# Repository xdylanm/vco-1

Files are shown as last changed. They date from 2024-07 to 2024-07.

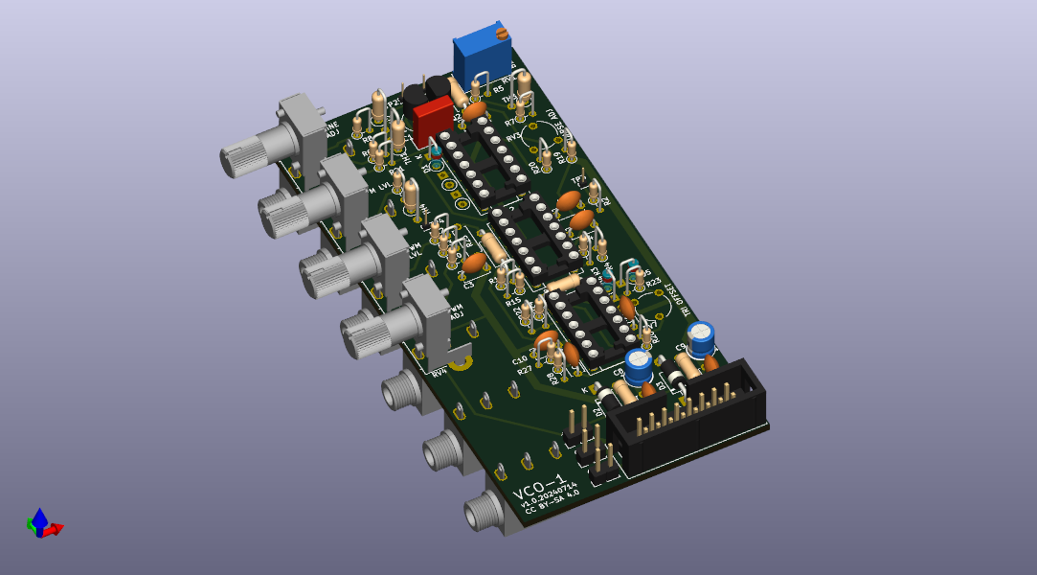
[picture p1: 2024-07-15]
docs/vco1_board3d.png

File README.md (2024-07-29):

# vco-1
Sawtooth core VCO based on Moritz Klein's DIY VCO. 

The general design and test description can be found on Moritz Klein's channel. The oscillator core is a ramp generator driven by a Schmitt trigger inverter and capacitor, controlled by an NPN. 

## Notes

* Using 2N3904 (NPN) and 2N3906 (PNP)
* Implemented a different triangle wave generator based on a precision rectifier circuit. The triangle generator sums a buffered ramp and an inverted, rectified ramp with balancing incorporated with a trimmer on the rectifier sum input.
* Made the coarse adjust an internal trimmer: "factory" tuning involves adjusting the coarse bias on the PNP base with both the coarse level adjust (high side) and divider scaling (low side). Might as well get that set on the bench then fine tune in operation.
* Option to configure the pulse output as a non-inverting summer (from Synth Mages) rather than open loop comparator.
* There are other variants without the Schmitt trigger inverter (e.g. hyestersis in another op-amp). There is also a 12V tolerant single Schmitt trigger inverter (TC4S584F) as an option for a future SMT version. 

## Oscillator Core Theory of Operation

The core of the oscillator is composed of the capacitor C1 and NPN BJT Q1. C1 is charged by the Schmitt trigger inverter U1A through D1 and discharged by Q1. Adjusting the bias on the base of Q1 adjusts the discharge rate of C1. 

The hysteresis on the CD40106 inverter is approximately 3V for a 12V supply (measured 2.8V on the bench). Assuming tuning over six octaves from 16Hz (~$C_0$ ) to 1024Hz (~$C_6$), the discharge time should range from approximately 1ms to 100ms. Using a 2.2nF capacitor for C1, the range of collector currents in Q1 is
$$
I_C \sim C\frac{dV}{dt} \to \left\{\begin{array}{ll}66nA & t_{discharge}=100ms \\ 6.6\mu A & t_{discharge}=1ms\end{array}\right.
$$
The basic model for the collector current is
$$
I_C = I_S \left(e^{\frac{V_{BE}}{V_T}} - 1\right)\to V_{BE}=V_T \ln\left(\frac{I_C}{I_S}+1\right)\simeq V_T(\ln I_C-\ln I_S)
$$
Assuming $I_S=10^{-13}A$, $V_{BE}$ ranges from 350mV to 470mV  ($V_T=26mV$). For larger $I_S$ , the low end of the range for $V_{BE}$ will be reduced (e.g. 290mV for $I_S=10^{-12}A$ ). The span of the range remains constant.

PNP BJT Q2 acts as a buffer in an emitter-follower configuration and counteracts the thermal response of Q1. Since the base voltage of Q1 should be below saturation (approximately 0.4V), there is an 11V drop across R1, which results in a bias current of approximately $11\mu A$ into the emitter and $V_{EB}\sim 0.5V$ for Q2. 

The  CV input is designed for a range between 0 and 5V (V/oct). $V_{BE}$ should vary by 90-120mV, which corresponds to a scaling of 0.018 to 0.024. The resistor divider formed by R6+TH1 and R5+RV1 creates this scaling: R6+TH1 is 110k such that R5+RV1 should range between 2k and 2.6k (R5=1.5k and RV1 ranges from 0 to 2k).

**Tuning Note:** Use an input that varies by 1V (e.g. alternate between 1V and 2V). If the difference in frequency between the same note in adjacent octaves is less than a factor of 2, increase RV1 to increase the gain of the resistor divider.

To set the low end of the range, the network including R19, R20, and RV3 is used to set a bias voltage. This is summed with the CV input through R7+TH3. As with the CV input, R7+TH3 creates a resistor divider with R5+RV1, which determines the gain applied to the bias voltage. Since $V_{EB}$ of Q2 is $\sim 0.5V$ and the low end of the range for $V_B$ of Q1 is 250-350mV, the base of Q2 is biased between -250mV and -150mV (more range here is better depending on the transistor characteristics - the tradeoff is tuning sensitivity). A factor of 40 reduces -12V to -300mV. R19 will limit the low end of the range and R20 will limit the high end. 

**Ideal Tuning**

* Assume $f_{C_0}=16Hz$ is the low frequency reference such that $t_{discharge,0} = 62.5ms$. 

* Use $\Delta V$ from the inverter hysteresis ($\Delta V = 3V$) and C1=2.2nF to obtain 
  $$
  I_{C,0} = C \frac{dV}{dt} = C \Delta V f_{C_0} = 2.2\cdot 10^{-9} \cdot 3 \cdot 16 = 106\mathrm{nA}
  $$

* Determine $V_{BE,0}$ and $\Delta V_{BE}$ , where $V_{BE}$ is the bias voltage to establish current $I_{C,0}$ through the NPN and $\Delta V_{BE}$ is the change in $V_{BE}$ to double the current,  
  $$
  \begin{align*}
  \Delta V_{BE} &\equiv nV_T \ln 2I_{C} - nV_T\ln I_C = nV_T \ln 2 \\
  V_{BE,0} &\equiv nV_T\left(\ln I_{C,0} - \ln I_{S}\right)
  \end{align*}
  $$

* Adjust the gain of the voltage divider (RV1) such that a change of 1V results in a doubling of the current $I_C$ (set $\Delta V_{BE} \approx 18\mathrm{mV}$).

* Adjust the offset with the coarse tuning pot such that the base of the NPN is biased to $V_{BE,0}$ when the input CV is 0V. 

## Assembly and Test

### 1. Power

* Populate the power input and filtering components at the bus connector. Verify the orientation of the polarity protection diodes D2 and D3.
* Connect the board to power and verify voltage levels.

### 2. Oscillator Core, Saw and Pulse Outputs

* Populate the input network (coarse adjust, fine adjust, CV and FM). Note that the board-edge pots (RV2 and RV6) must have their leads trimmed flush with the bottom of the board so that the mono jacks mount flush. Install the pots first and jacks later.
* Populate the transistors Q1 and Q2, socket and 40106 inverter (U1), diode D1 and capacitor C1.
* Populate the socket and TL074 op amp (U2) and the components for the pulse and saw outputs. This is required to generated a buffered signal from the oscillator core at TP9 (or after the DC block at TP3)
* Tune the oscillator (16Hz for a 0V input on CV, 32Hz for 1V, etc.) by adjusting RV1 and RV3. RV1 sets the gain of the voltage divider and should be adjust such that a 1V difference results in a frequency doubling. Next, adjust RV3 to set the base frequency. There is some coupling between the resistive networks, so iteration is required.
* Check the levels for the Saw and Pulse outputs (confirm ~10Vpp). Check the PWM adjustment and confirm a full range of pulse widths.

### 3. Triangle Output

* Populate the discrete components (watch the orientation on diodes D4 and D5) and the socket and TL074 op amp (U3). Populate the last jack.
* Power on the board and check the Triangle output. Adjust RV7 to balance the triangle (it won't be perfect at all frequencies; there is a short spike at the transition).

## Changes

#### V1.1.20240726

* Added additional test points, fixed test point pad to fit standard 0.1" header pins
* R14 to 82k (not tested; pulse out Vpp measured at 8.5V with 68k)
* Added C13 to remove spike in saw output
* R26 to 68k to fix level for triangle output range (now 9.6Vpp)

#### V1.0.20240714

Original PCB

## References

1. Moritz Klein: [DIY VCO Series](https://youtube.com/playlist?list=PLHeL0JWdJLvTuGCyC3qvx0RM39YvopVQN&si=mLFLNtdBjMHdq1OI)
2. Precision rectifier circuit: [Circuit Digest](https://circuitdigest.com/electronic-circuits/half-wave-and-full-wave-precision-rectifier-circuit-using-op-amp)
3. Synth Mages: [DIY VCO variant](https://gitea.circuitlocution.com/synth_mages/MK_VCO)

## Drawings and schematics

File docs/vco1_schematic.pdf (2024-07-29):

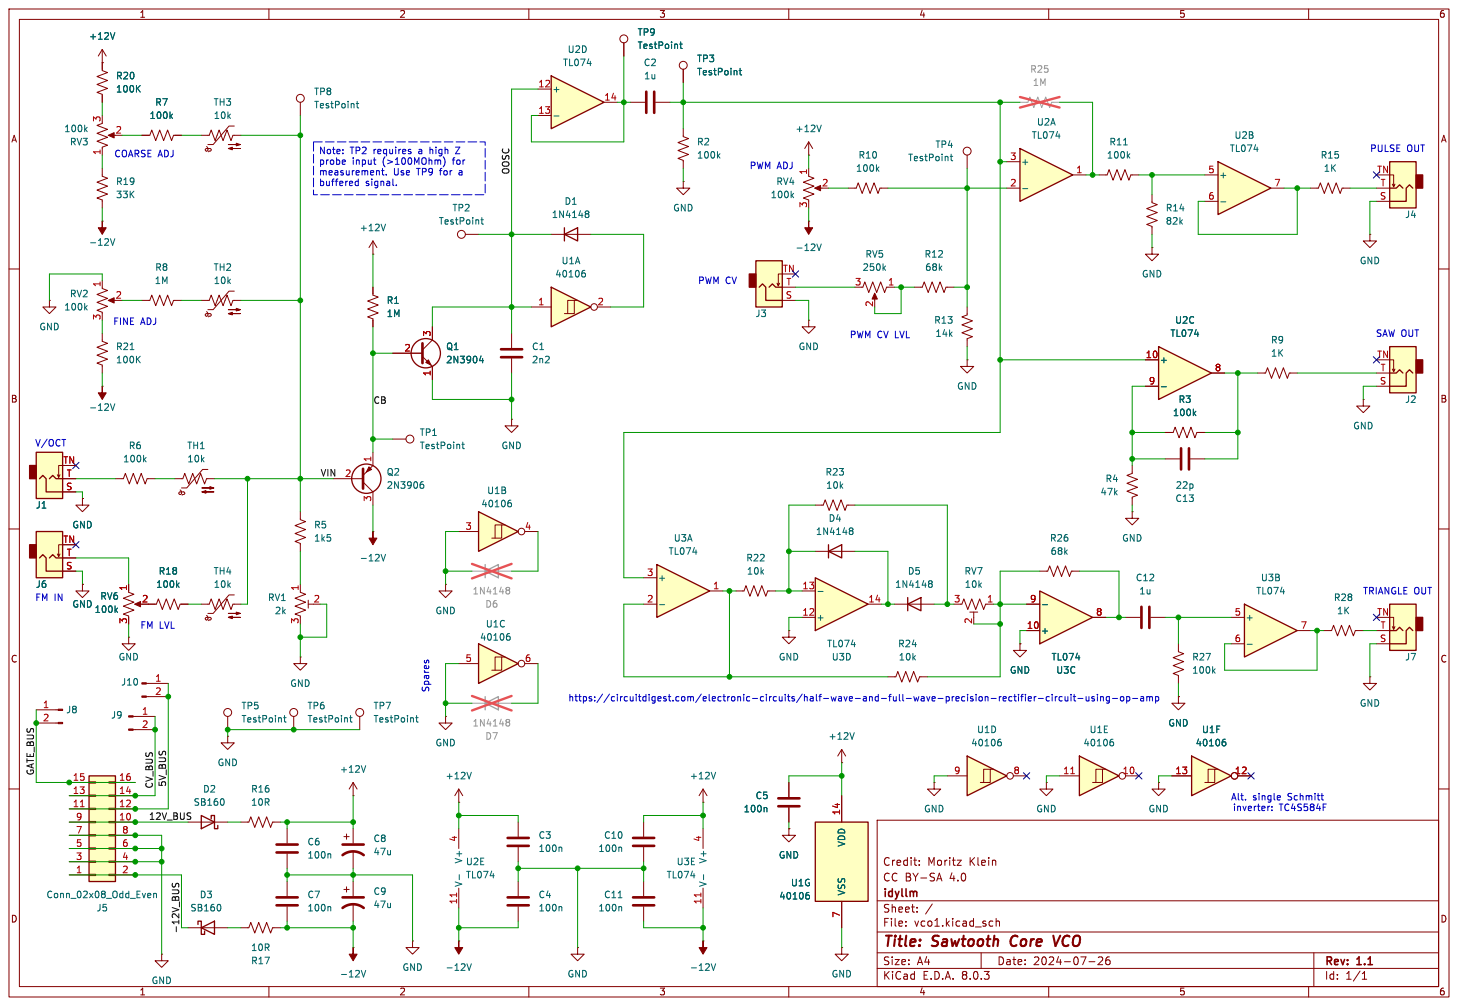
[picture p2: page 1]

SAW OUT Note: TP2 requires a high Z

idyllm
File: vco1.kicad_sch Sheet: /
Id: 1/1 Title: Sawtooth Core VCO

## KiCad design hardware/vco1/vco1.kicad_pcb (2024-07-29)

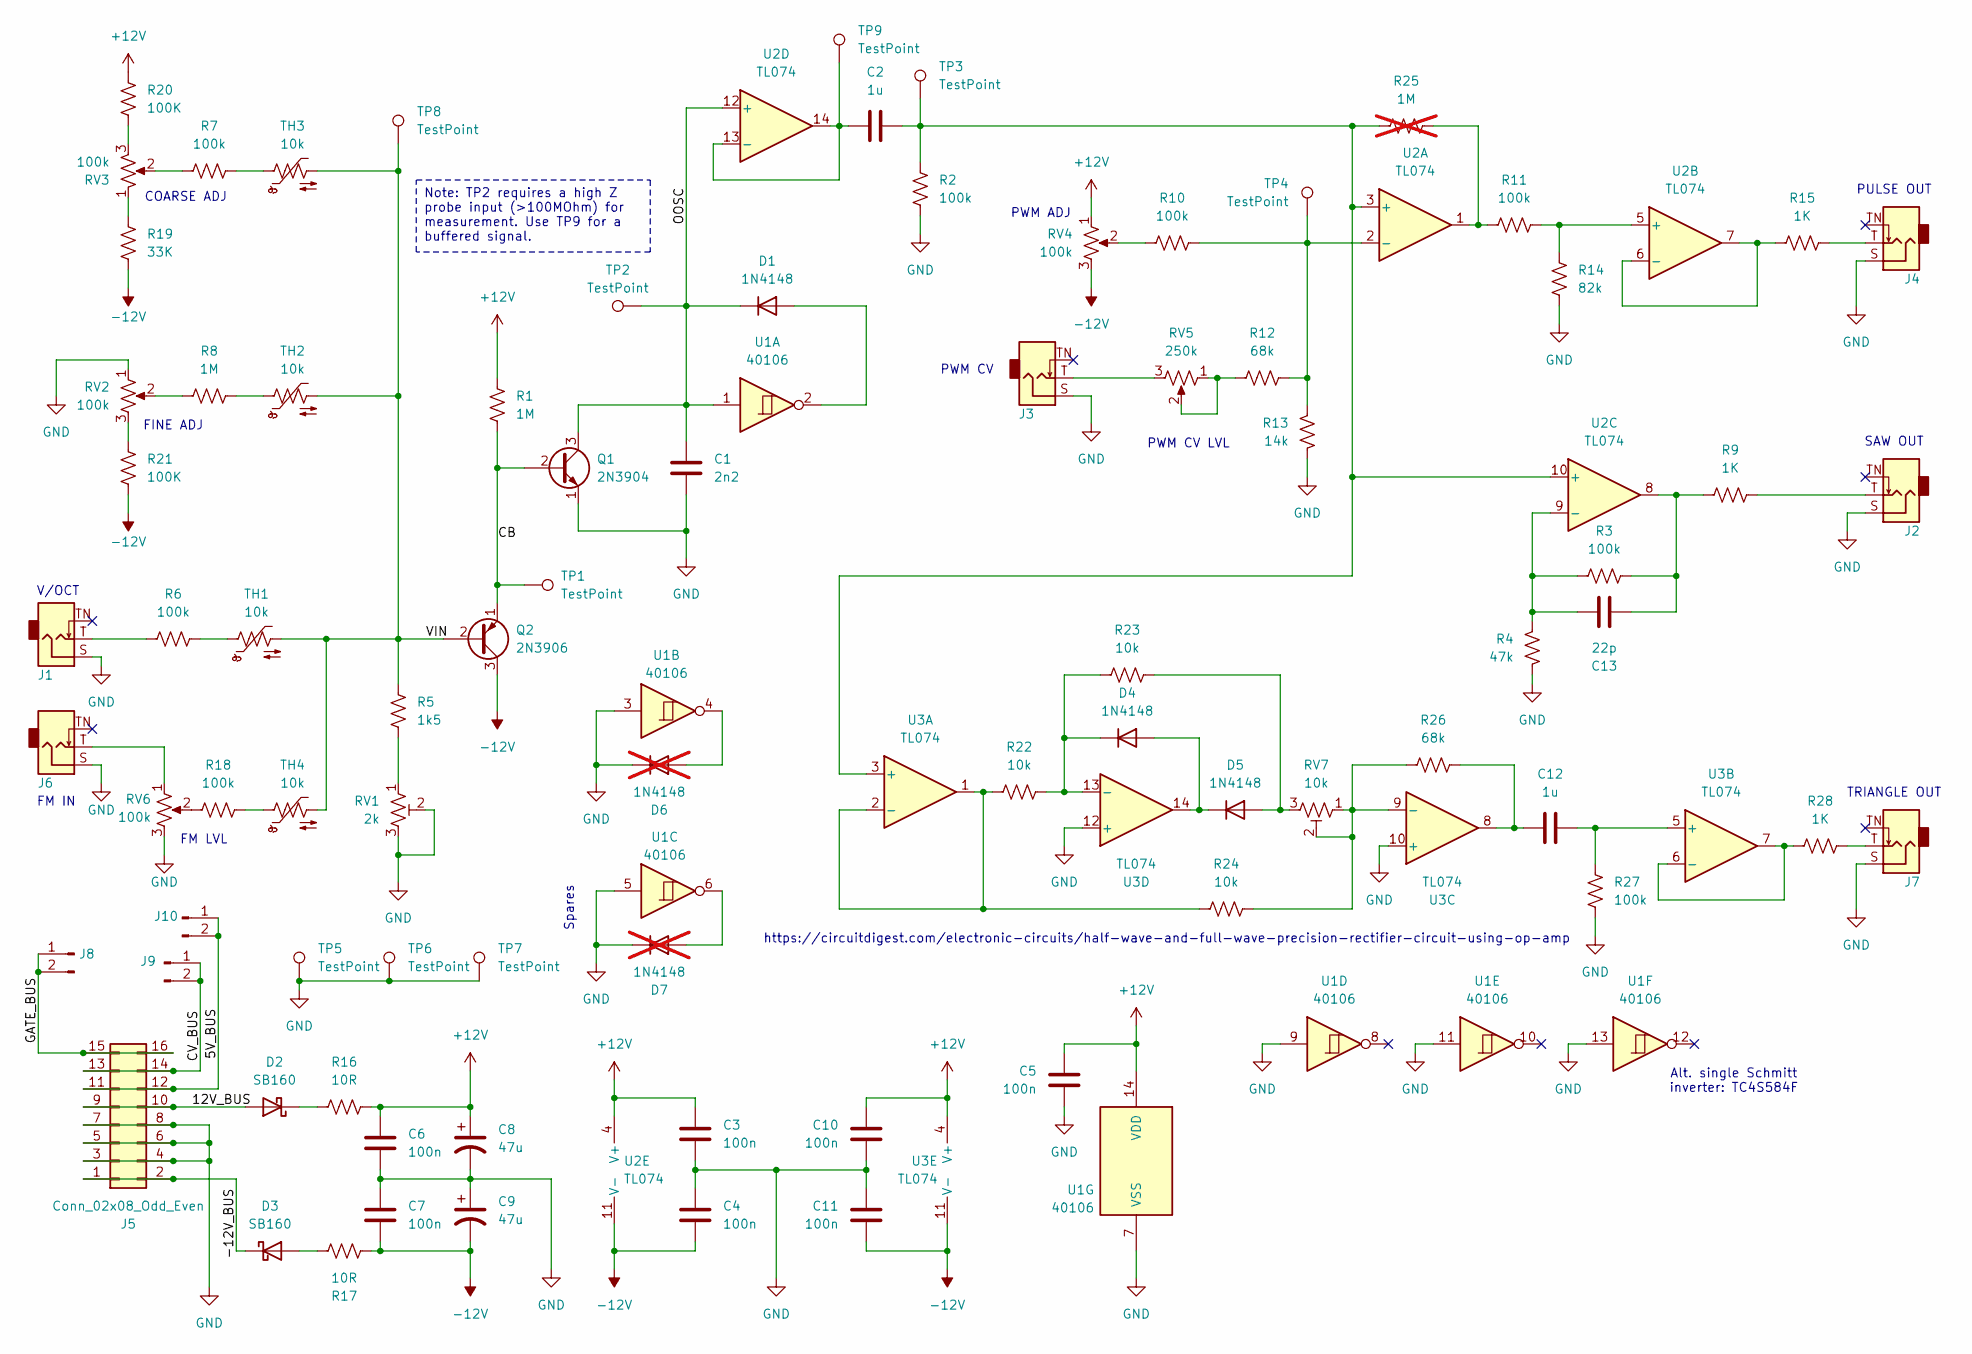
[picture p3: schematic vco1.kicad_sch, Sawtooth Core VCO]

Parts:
C1: 2n2; C_Rect_L7.2mm_W2.5mm_P5.00mm_FKS2_FKP2_MKS2_MKP2
C2, C12: 1u; C_Disc_D5.0mm_W2.5mm_P5.00mm
C3, C4, C5, C6, C7, C10, C11: 100n; C_Disc_D5.0mm_W2.5mm_P5.00mm
C8, C9: 47u; CP_Radial_D5.0mm_P2.50mm
C13: 22p; C_Disc_D5.0mm_W2.5mm_P5.00mm
D1, D4, D5: 1N4148; D_DO-35_SOD27_P2.54mm_Vertical_KathodeUp
D2, D3: SB160; D_DO-41_SOD81_P10.16mm_Horizontal
D6, D7: 1N4148; D_DO-35_SOD27_P2.54mm_Vertical_KathodeUp; not fitted
J1, J2, J3, J4, J6, J7: AudioJack2_SwitchT; CONN_MJ-3502
J5: Conn_02x08_Odd_Even; IDC-Header_2x08_P2.54mm_Vertical
J8, J9, J10: Conn_01x02_Pin; PinHeader_1x02_P2.54mm_Vertical
Q1: 2N3904; TO-92_Inline_Wide
Q2: 2N3906; TO-92_Inline_Wide
R1: 1M; R_Axial_DIN0207_L6.3mm_D2.5mm_P7.62mm_Horizontal
R2, R3, R6, R7, R10, R18, R27: 100k; R_Axial_DIN0204_L3.6mm_D1.6mm_P2.54mm_Vertical
R4: 47k; R_Axial_DIN0204_L3.6mm_D1.6mm_P2.54mm_Vertical
R5: 1k5; R_Axial_DIN0204_L3.6mm_D1.6mm_P2.54mm_Vertical
R8: 1M; R_Axial_DIN0204_L3.6mm_D1.6mm_P2.54mm_Vertical
R9: 1K; R_Axial_DIN0207_L6.3mm_D2.5mm_P7.62mm_Horizontal
R11: 100k; R_Axial_DIN0207_L6.3mm_D2.5mm_P10.16mm_Horizontal
R12, R26: 68k; R_Axial_DIN0204_L3.6mm_D1.6mm_P2.54mm_Vertical
R13: 14k; R_Axial_DIN0204_L3.6mm_D1.6mm_P2.54mm_Vertical
R14: 82k; R_Axial_DIN0204_L3.6mm_D1.6mm_P2.54mm_Vertical
R15, R28: 1K; R_Axial_DIN0204_L3.6mm_D1.6mm_P2.54mm_Vertical
R16, R17: 10R; R_Axial_DIN0207_L6.3mm_D2.5mm_P7.62mm_Horizontal
R19: 33K; R_Axial_DIN0204_L3.6mm_D1.6mm_P2.54mm_Vertical
R20, R21: 100K; R_Axial_DIN0204_L3.6mm_D1.6mm_P2.54mm_Vertical
R22, R23, R24: 10k; R_Axial_DIN0204_L3.6mm_D1.6mm_P2.54mm_Vertical
R25: 1M; R_Axial_DIN0207_L6.3mm_D2.5mm_P7.62mm_Horizontal; not fitted
RV1: 2k; Potentiometer_Bourns_3296W_Vertical
RV2, RV4, RV6: 100k; Potentiometer_Bourns_PTV09A-2_Single_Horizontal_3D
RV3: 100k; Potentiometer_Piher_PT-6-V_Vertical
RV5: 250k; Potentiometer_Bourns_PTV09A-2_Single_Horizontal_3D
RV7: 10k; Potentiometer_Piher_PT-6-V_Vertical
TH1, TH2, TH3, TH4: 10k; R_Axial_DIN0207_L6.3mm_D2.5mm_P2.54mm_Vertical
TP1, TP2, TP3, TP4, TP5, TP6, TP7, TP8, TP9: TestPoint; PinHeader_1x01_P2.54mm_Vertical
U1: 40106; DIP-14_W7.62mm_Socket
U2, U3: TL074; DIP-14_W7.62mm_Socket

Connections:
+12V: C3.1, C5.1, C6.1, C8.1, C10.1, R1.1, R16.2, R20.1, RV4.1, U1.14 (VDD), U2.4 (V+), U3.4 (V+)
-12V: C4.2, C7.2, C9.2, C11.2, Q2.3 (C), R17.1, R19.1, R21.2, RV4.3, U2.11 (V-), U3.11 (V-)
/5V_BUS: J5.11, J5.12, J10.1, J10.2
/12V_BUS: D2.2 (A), J5.9, J5.10
/-12V_BUS: D3.1 (K), J5.1, J5.2
/CB: Q1.2 (B), Q2.1 (E), R1.2, TP1.1
/CV_BUS: J5.13, J5.14, J9.1, J9.2
/GATE_BUS: J5.15, J5.16, J8.1, J8.2
/OOSC: C1.1, D1.1 (K), Q1.3 (C), TP2.1, U1.1, U2.12 (+)
/VIN: Q2.2 (B), R5.1, TH1.2, TH2.2, TH3.2, TH4.2, TP8.1
GND: C1.2, C3.2, C4.1, C5.2, C6.2, C7.1, C8.2, C9.1, C10.2, C11.1, D6.1 (K), D7.1 (K), J1.S, J2.S, J3.S, J4.S, J5.3, J5.4, J5.5, J5.6, J5.7, J5.8, J6.S, J7.S, Q1.1 (E), R2.2, R4.1, R13.1, R14.1, R27.2, RV1.2, RV1.3, RV2.1, RV6.3, TP5.1, TP6.1, TP7.1, U1.3, U1.5, U1.7 (VSS), U1.9, U1.11, U1.13, U3.10 (+), U3.12 (+)
unnamed: C12.1, R26.1, U3.8
unnamed: C13.2, R3.2, R9.1, U2.8
unnamed: D1.2 (A), U1.2
unnamed: D2.1 (K), R16.1
unnamed: D3.2 (A), R17.2
unnamed: D4.2 (A), D5.1 (K), U3.14
unnamed: D4.1 (K), R22.1, R23.2, U3.13 (-)
unnamed: D5.2 (A), R23.1, RV7.3
unnamed: D6.2 (A), U1.4
unnamed: D7.2 (A), U1.6
unnamed: J1.T, R6.1
unnamed: J2.T, R9.2
unnamed: J3.T, RV5.3
unnamed: J4.T, R15.2
unnamed: J6.T, RV6.1
unnamed: J7.T, R28.2
unnamed: R5.2, RV1.1
unnamed: R6.2, TH1.1
unnamed: R7.1, RV3.2
unnamed: R7.2, TH3.1
unnamed: R8.1, RV2.2
unnamed: R8.2, TH2.1
unnamed: R10.1, RV4.2
unnamed: R11.1, R25.2, U2.1
unnamed: R12.1, RV5.1, RV5.2
unnamed: R18.1, RV6.2
unnamed: R18.2, TH4.1
unnamed: R19.2, RV3.1
unnamed: R20.2, RV3.3
unnamed: R21.1, RV2.3
unnamed: C2.2, R2.1, R25.1, TP3.1, U2.3 (+), U2.10 (+), U3.3 (+)
unnamed: R10.2, R12.2, R13.2, TP4.1, U2.2 (-)
unnamed: R11.2, R14.2, U2.5 (+)
unnamed: R15.1, U2.6 (-), U2.7
unnamed: C13.1, R3.1, R4.2, U2.9 (-)
unnamed: C2.1, TP9.1, U2.13 (-), U2.14
unnamed: R22.2, R24.2, U3.1, U3.2 (-)
unnamed: C12.2, R27.1, U3.5 (+)
unnamed: R28.1, U3.6 (-), U3.7
unnamed: R24.1, R26.2, RV7.1, RV7.2, U3.9 (-)

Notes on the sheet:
Note: TP2 requires a high Z probe input (>100MOhm) for measurement. Use TP9 for a buffered signal.
TRIANGLE OUT
PWM ADJ
FM IN
COARSE ADJ
FINE ADJ
https://circuitdigest.com/electronic-circuits/half-wave-and-full-wave-precision-rectifier-circuit-using-op-amp
PULSE OUT
PWM CV
PWM CV LVL
FM LVL
Alt. single Schmitt inverter: TC4S584F
SAW OUT
Spares
V/OCT

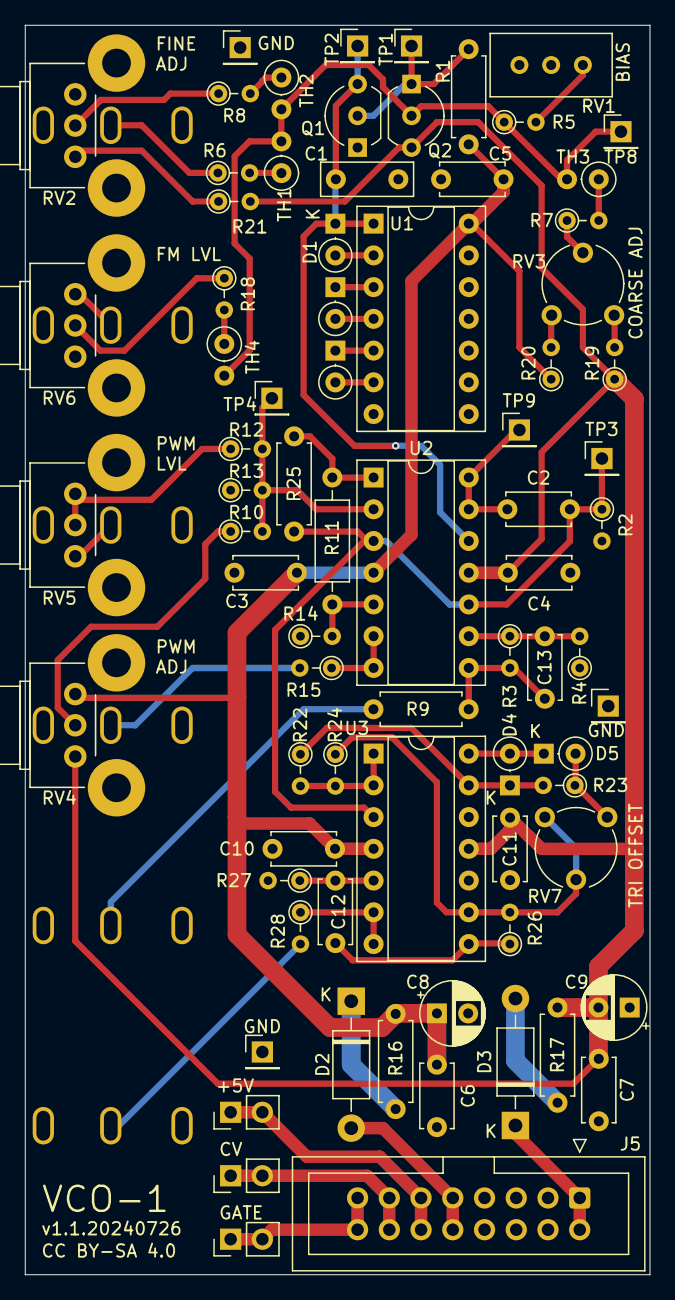
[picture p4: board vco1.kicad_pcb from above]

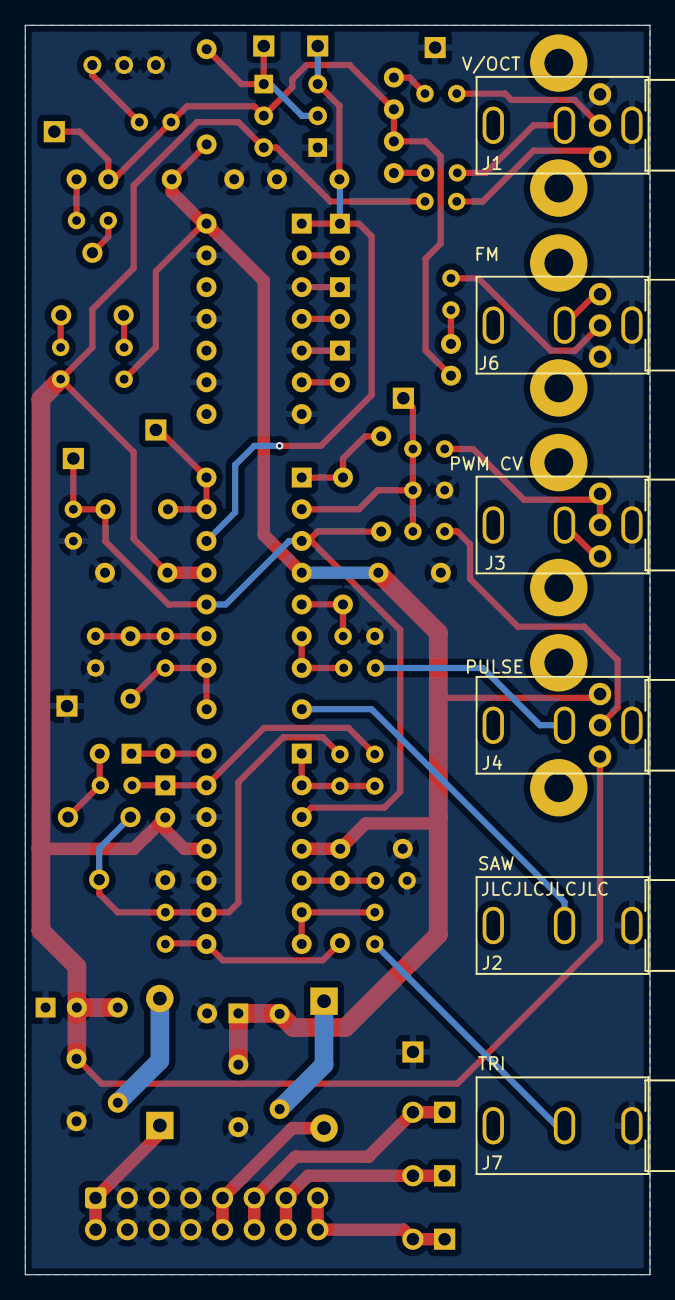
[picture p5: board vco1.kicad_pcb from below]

Board: 2 copper layers, 50.0 x 100.0 mm, 83 parts (6 on the bottom side), 51 nets.

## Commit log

2024-07-15 initial board for VCO
    [vco1.kicad_pcb, vco1.kicad_sch]
2024-07-15 added PDF of schematic & board rendering
    [vco1.kicad_pcb]
2024-07-15 Added a PCB for a front panel (aluminium by JLC)
    [panel.kicad_pcb, panel.kicad_sch, vco1.kicad_pcb]
2024-07-27 added more test points and documentation. Currently cannot adjust to f_osc < 800Hz
    [vco1.kicad_pcb, vco1.kicad_sch]
2024-07-29 Update schematic and board to v1.1 based on initial test from v1 PCB. Changes in README.md
    [vco1.kicad_pcb, vco1.kicad_sch]

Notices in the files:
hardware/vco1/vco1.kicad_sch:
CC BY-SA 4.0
